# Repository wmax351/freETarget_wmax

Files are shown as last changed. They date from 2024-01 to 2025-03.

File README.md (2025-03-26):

# freETarget minimalistic

This is a fork from the forked minimalistic version. The aim is to build a version based on widely available parts only, with electronics cost of less than 30 USD. I have added an LM335 temperature sensor, and altitude compensation. 

## What is frETagret minimalistic ##

This version requires only the following electronics parts which you can source directly from you provider of choice:

**1x Arduino mega 2560**
**4x KY-037 microphone units**
**LM335 temp sensor**

This is possible due to a software change, which takes full advantage of the ATmega2560 capabilities. In the original version, shot timing is achieved using external timing infrastructure. The ATmega2560 has 6 timers, with 4 of them offering an Input Capture Unit (ICU). Using this mode, the timer values are immediately stored when a pin changes and an interrupt is fired, so there is no software jitter. One of the hurdles to overcome is in the design of the Arduino mega board, which does not connect all the ICU pins to the headers. This was overcome by bridging the respective to pins to adjacent fee ones with a fine-tipped soldering iron:

**Bridge PD4, PD5, PD6 and PD7**

**Bridge PE5, PE6, PE7**

Once done, connect the digital outputs of the microphone boards as follows:

**North: pin 38, East: pin 3, South: pin 49, West: pin 48**
**Vcc and GND to the respective Arduino pins**

**LM335 is added to A1 and GND (can use reset switch ground)**
Internal pullup is used for A1. 

For the mics to trigger all at the same level, set the pot voltage to a value of your finding (e.g. 0.380 V in my case).

Please refer to the original software for full building instructions.

A word to accuracy and precision of this version. I have not fully specified these parameters. While the timers work without a jitter (this vas verified and confirmed), there might be a diminished performance based on the selected microphone boards. Temperature sensor added back.

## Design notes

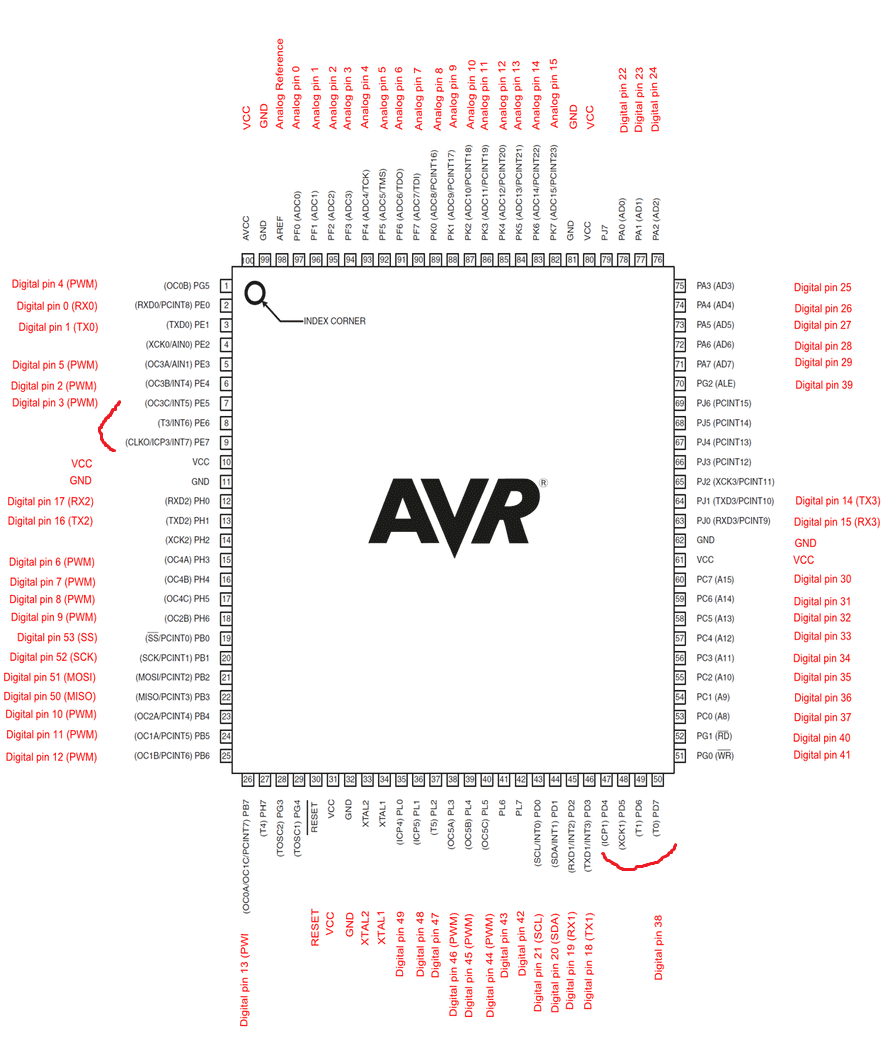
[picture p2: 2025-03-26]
PinMap2560big_Rev2.png

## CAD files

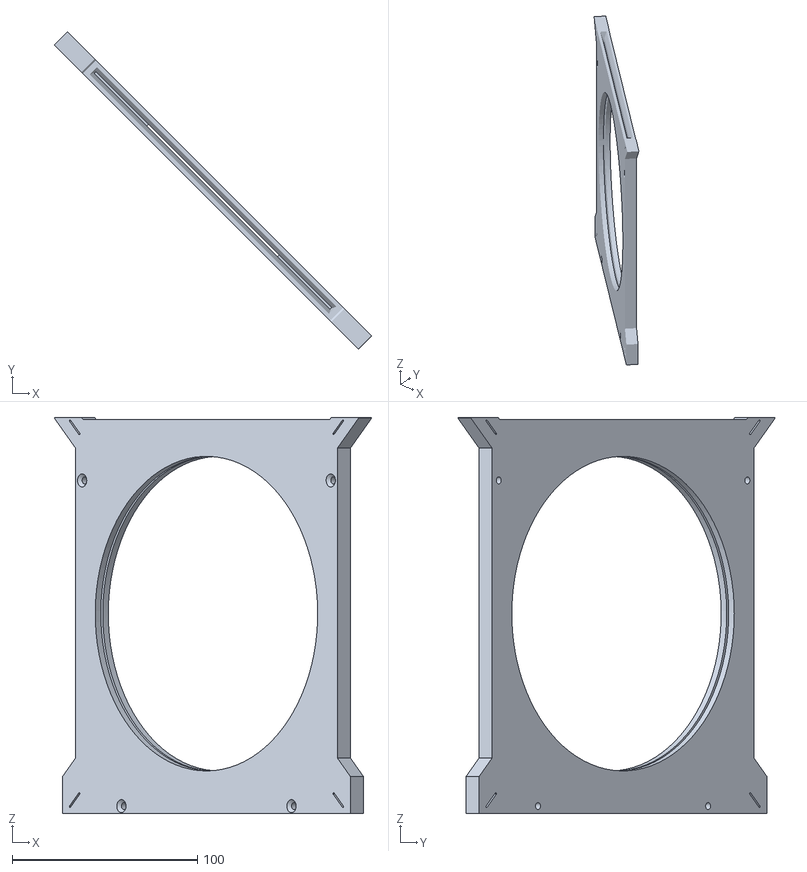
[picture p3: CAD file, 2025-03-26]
3d Print/Target Holder and Sensor Plate.stl
171.5 x 171.5 x 214.0

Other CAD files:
3d Print/Front Plate.ipt
3d Print/OldVersions/Front Plate.0002.ipt
3d Print/OldVersions/Sensor ky-037.0004.ipt
3d Print/OldVersions/Target Holder With Sensors.0013.iam
3d Print/OldVersions/Target Holder and Sensor Plate.0033.ipt
3d Print/Sensor ky-037.ipt
3d Print/Sensor ky-037_MIR.ipt
3d Print/Sensor ky-037_MIR1.ipt
3d Print/Sensor ky-037_MIR_MIR.ipt
3d Print/Sensor mounts.ipt
3d Print/Target Holder With Sensors.iam
3d Print/Target Holder and Sensor Plate.ipt

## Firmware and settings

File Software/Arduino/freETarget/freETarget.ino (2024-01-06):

/*----------------------------------------------------------------
 * 
 * freETarget        
 * 
 * Software to run the Air-Rifle / Small Bore Electronic Target
 * 
 *-------------------------------------------------------------*/
#include "freETarget.h"
#include "gpio.h"
#include "compute_hit.h"
#include "analog_io.h"
#include "json.h"
#include "EEPROM.h"
#include "nonvol.h"
#include "mechanical.h"
#include "diag_tools.h"
#include "esp-01.h"
#include "timer.h"
#include "token.h"

shot_record_t record[SHOT_STRING];          //Array of shot records
volatile unsigned int this_shot;            // Index into the shot array  
volatile unsigned int last_shot;            // Last shot processed.

double        s_of_sound;                   // Speed of sound
unsigned int  shot = 0;                     // Shot counter
unsigned int  face_strike = 0;              // Miss Face Strike interrupt count
unsigned int  is_trace = 0;                 // Turn off tracing
unsigned int  rapid_count = 0;              // Number of shots to be expected in Rapid Fire
unsigned int  tabata_state;                 // Tabata state
unsigned int  shot_number;                  // Shot Identifier
volatile unsigned long  keep_alive;         // Keep alive timer
volatile unsigned long  tabata_rapid_timer; // Tabita or Rapid fire timer
volatile unsigned long  in_shot_timer;      // Time inside of the shot window
volatile unsigned long  power_save;         // Power save timer
volatile unsigned long  token_tick;         // Token ring watchdog
volatile unsigned long  gpt;                // General purpose timer

const char* namesensor[] = { "TARGET",                                                                                           //  0
                        "1",      "2",        "3",     "4",      "5",       "6",       "7",     "8",     "9",      "10",    //  1
                        "DOC",    "DOPEY",  "HAPPY",   "GRUMPY", "BASHFUL", "SNEEZEY", "SLEEPY",                            // 11
                        "RUDOLF", "DONNER", "BLITZEN", "DASHER", "PRANCER", "VIXEN",   "COMET", "CUPID", "DUNDER",          // 18  
                        "ODIN",   "WODEN",   "THOR",   "BALDAR",                                                            // 26
                        0};
                  
const char nesw[]   = "NESW";                  // Cardinal Points
const char to_hex[] = "0123456789ABCDEF";      // Quick Hex to ASCII
static void bye(void);                         // Say good night Gracie
static long tabata(bool reset_time);           // Tabata state machine
static bool discard_tabata(void);              // TRUE if the shot should be discarded 

#define TABATA_OFF          0         // No tabata cycles at all
#define TABATA_REST         1         // Tabata is doing nothing (typically 60 seconds)
#define TABATA_WARNING      2         // Time the warning LED is on (typically 2 seconds)
#define TABATA_DARK         3         // Time the warning LED is off before the shot (typically 2 seconds)
#define TABATA_ON           4         // Time the TABATA lED is on (typically 5 seconds)

/*----------------------------------------------------------------
 * 
 * function: setup()
 * 
 * brief: Initialize the board and prepare to run
 * 
 * return: None
 * 
 *--------------------------------------------------------------*/

void setup(void) 
{    
/*
 *  Setup the serial port
 */
  Serial.begin(115200, SERIAL_8N1);
  AUX_SERIAL.begin(115200, SERIAL_8N1); 
  DISPLAY_SERIAL.begin(115200, SERIAL_8N1); 
  POST_version();                         // Show the version string on all ports
  
  init_gpio();  
  init_sensors();
  init_analog_io();
  init_timer();
  set_LED('*', '.', '.');                 // Hello World
  read_nonvol();
  
  is_trace = 0; // DLT_CRITICAL;                // Turn on tracing ToDo change back

/*
 *  Set up the port pins
 */
  timer_new(&keep_alive,    (unsigned long)json_keep_alive * ONE_SECOND); // Keep alive timer
  timer_new(&tabata_rapid_timer,   0);                                    // Free running tabata or rapid fire timer
  timer_new(&in_shot_timer, FULL_SCALE);                                  // Time inside of the shot window
  timer_new(&power_save,    (unsigned long)(json_power_save) * (long)ONE_SECOND * 60L);// Power save timer
  timer_new(&token_tick,    5 * ONE_SECOND);                              // Token ring watchdog
  timer_new(&gpt,           0);                                           // General purpose timer
  
  randomSeed( analogRead(V_REFERENCE));   // Seed the random number generator
  
/*
 * Initialize variables
 */
   set_LED('.', '.', '*');                // Hello World
   tabata(true);                          // Reset the Tabata timers
  
/*
 * Run the power on self test
 */
  set_LED('*', '.', '*');                 // Hello World
  while ( (POST_counters() == false)      // If the timers fail
              && !DLT(DLT_CRITICAL))          // and not in trace mode (DIAG jumper installed)
  {
    Serial.print(T("POST_2 Failed\r\n"));// Blink the LEDs
    blink_fault(POST_COUNT_FAILED);       // and try again
  }
  
/* 
 *  Setup the timer
 */
  set_LED('.', '*', '.');                 // Hello World

  if ( DLT(DLT_CRITICAL) )
  {
    Serial.print(T("Starting timers"));
  }

  enable_timer_interrupt();
     
/*
 * Initialize the WiFi or token ring if available
 */

   set_LED('*', '*', '.');                 // Hello World
   esp01_init();                         // Prepare the WiFi channel if installed
   
/*
 * Ready to go
 */ 
  multifunction_switch();
  set_LED('*', '*', '*');                 // Hello World
  set_LED_PWM(json_LED_PWM);
  POST_LEDs();                            // Cycle the LEDs
  set_LED(LED_READY);                     // to a client, then the RDY light is steady on
  
  if ( DLT(DLT_CRITICAL) )
  {
    Serial.print(T("Clearing serial buffers"));
  }
  while ( available_all() )
  {
    get_all();                                // Flush any garbage before we start up
  }
  
  DLT(DLT_CRITICAL); 
  Serial.print(T("Finished startup\n\r"));
  show_echo();
  return;
}

/*----------------------------------------------------------------
 * 
 * function: loop()
 * 
 * brief: Main control loop
 * 
 * return: None
 * 
 *----------------------------------------------------------------
 */
#define SET_MODE      0           // Set the operating mode
#define ARM        (SET_MODE+1)   // State is ready to ARM
#define WAIT       (ARM+1)        // ARM the circuit and wait for a shot
#define REDUCE     (WAIT+1)     // Reduce the data
#define FINISH     (REDUCE+1)     // Wait for the shot to end

unsigned int state = SET_MODE;
unsigned int old_state = ~SET_MODE;

unsigned int  sensor_status;          // Record which sensors contain valid data
unsigned int  location;               // Sensor location 

char* loop_name[] = {"SET_MODE", "ARM", "WAIT", "AQUIRE", "REDUCE", "FINISH" };

void loop() 
{
  unsigned int i, j;              // Iteration Counter
  
/*
 * First thing, handle polled devices
 */
  multifunction_switch();         // Read the switches
  tabata(false);                  // Update the Tabata state

/*
 * Take care of any commands coming through
 */

  switch (json_token )
  {
    case TOKEN_WIFI:
      esp01_receive();
      break;

    case TOKEN_MASTER:
      if ( token_tick == 0)             // Time to check the token ring?
      {
        token_init();                   // Request an enumeration
        if ( my_ring == TOKEN_UNDEF )
        {
          token_tick = ONE_SECOND * 5;  //  Waiting to start up
        }
        else
        {
          token_tick = ONE_SECOND * 60; // Just check
        }
      }

    case TOKEN_SLAVE:
      token_poll();                     // Check the token ring
      break;
  }
    
  if ( read_JSON() )
  {
    power_save = (long)json_power_save * 60L * (long)ONE_SECOND;        // Reset the power down timer if something comes in
  }

/*
 * Take care of the TCPIP keep alive
 */
 if ( (json_keep_alive != 0)
    && (keep_alive == 0) )              // Time in seconds
 {
    send_keep_alive();
    keep_alive = json_keep_alive * ONE_SECOND;
 }

/*
 * Take care of the low power mode
 */
  if ( (json_power_save != 0 ) 
       && (power_save == 0) )                         // Time in minutes
  {
    bye();                                            // Dim the lights
    power_save = (unsigned long)json_power_save * (unsigned long)ONE_SECOND * 60L;   // Came back. 
    state = SET_MODE;                                 // Reset everything just in case
  }

/*
 * Cycle through the state machine
 */
  if ( (state != old_state) 
      && DLT(DLT_APPLICATION) )
  {
    Serial.print(T("Loop State: ")); Serial.print(loop_name[state]);;
  } 
  old_state = state;
  
  switch (state)
  {
/*
 *  Check for special operating modes
 */
  default:
  case SET_MODE:    // Start of the loop
    state = set_mode();
    break;

  case ARM:         // Arm the circuit
    state = arm();
    break;

  case WAIT:        // Wait for the shot to appear
    state = wait();
    break;

  case REDUCE:     // Reduce the result of one or more shots
    state = reduce();
    break;

  case FINISH:     // Finish up the cycle by movint the witness paper
    state = finish();
    break;
  }
  
/*
 * End of the loop. return
 */
  return;
}

/*----------------------------------------------------------------
 * 
 * function: set_mode()
 * 
 * brief: Set up the modes for the next string of shots
 * 
 * return: Exit to the ARM state
 * 
 *----------------------------------------------------------------
 *
 * The shot cycle is about to start.
 * 
 * This initializes the variables.
 * 
 * The illumination LED is set depending on whether or not 
 * the Tabata or Rapid fire feature is enabled
 *
 *--------------------------------------------------------------*/
 unsigned int set_mode(void)
 {
  unsigned int i;

  for (i=0; i != SHOT_STRING; i++)
  {
    record[i].face_strike = 100;    // Disable the shot record
  }

  if ( json_tabata_enable || json_rapid_enable ) // If the Tabata or rapid fire is enabled, 
  {
    set_LED_PWM_now(0);             // Turn off the LEDs
    set_LED(LED_TABATA_ON);         // Just turn on X
    json_rapid_enable = 0;          // Disable the rapid fire
  }                                 // Until the session starts
  else
  {
    set_LED_PWM(json_LED_PWM);      // Keep the LEDs ON
  }

/*
 * Proceed to the ARM state
 */
  return ARM;                      // Carry on to the target
 }
    
/*----------------------------------------------------------------
 * 
 * function: arm()
 * 
 * brief:  Arm the circuit and check for errors
 * 
 * return: Exit to the WAIT state if the circuit is ready
 *         Stay in the ARM state if a hardware fault was detected
 * 
 *----------------------------------------------------------------
 *
 * The shot cycle is about to start.
 * 
 * This initializes the variables.
 * 
 * The illumination LED is set depending on whether or not 
 * the Tabata or Rapid fire feature is enabled
 *
 *--------------------------------------------------------------*/
unsigned int arm(void)
{
  face_strike = 0;                  // Reset the face strike count
  if ( json_send_miss
        && (json_face_strike != 0))
  {
    enable_face_interrupt();        // Turn on the face strike interrupt
  }

  stop_timers();
  arm_timers();                     // Arm the counters
  
  sensor_status = is_running();     // and immediatly read the status
  if ( sensor_status == B00001111 )         // After arming, the sensor status should all still run
  { 
    if ( DLT(DLT_APPLICATION) )
    {
      Serial.print(T("Waiting..."));
    }  
    return WAIT;                   // Fall through to WAIT
  }

/*
 * The sensors are tripping, display the error
 */
  if (!(sensor_status & B0000001))
  {
    Serial.print(T("\r\n{ \"Fault\": \"NORTH\" }"));
    set_LED(NORTH_FAILED);           // Fault code North
    delay(ONE_SECOND);
  }
  if ((!sensor_status & B00000010))
  {
    Serial.print(T("\r\n{ \"Fault\": \"EAST\" }"));
    set_LED(EAST_FAILED);           // Fault code East
    delay(ONE_SECOND);
  }
  if (!(sensor_status & B00000100))
  {
    Serial.print(T("\r\n{ \"Fault\": \"SOUTH\" }"));
    set_LED(SOUTH_FAILED);         // Fault code South
    delay(ONE_SECOND);
  }
  if (!(sensor_status & B00001000))
  {
    Serial.print(T("\r\n{ \"Fault\": \"WEST\" }"));
    set_LED(WEST_FAILED);         // Fault code West
    delay(ONE_SECOND);
  }

/*
 * Got an error, try to arm again
 */
  return ARM;
}
   
/*----------------------------------------------------------------
 * 
 * function: wait()
 * 
 * brief: Wait here for a shot to be fired
 * 
 * return: Exit to the WAIT state if the circuit is ready
 *         Stay in the ARM state if a hardware fault was detected
 * 
 *----------------------------------------------------------------
 *
 * This loop is executed indefinitly until a shot is detected
 * 
 * In this loop check
 *    - State of the WiFi interface
 *
 *--------------------------------------------------------------*/
static bool rapid_once;

unsigned int wait(void)
{
/*
 * Monitor the WiFi and blink if WiFi is present but not connected
 * Set RDY to solid red if there is a connection to the PC client
 */
  if ( ((json_token == TOKEN_WIFI) && ((esp01_is_present() == false) || esp01_connected() ))         // If the esp01 is not present, or connected
          || ((json_token != TOKEN_WIFI) && (my_ring != TOKEN_UNDEF)) )
  {
    set_LED(LED_READY);                 // to a client, then the RDY light is steady on
  }
  else
  {
    if ( (millis() / 1000) & 1 )       // Otherwise blink the RDY light
    {
      set_LED(LED_READY);
    }
    else
    {
      set_LED(LED_OFF);
    }
  }

/*
 * Check to see if the time has run out if there is a rapid fire event in progress
 */

  if (json_rapid_enable == 1)         // The rapid fire timer has been turned on
  {
    if (tabata_rapid_timer == 0 )     // Do this until the timer expires
    {
      set_LED_PWM_now(0);
      Serial.print(T("{\"RAPID_OVER\": 0}\r\n"));
      return FINISH;                   // Finish this rapid fire cycle
    }
    else
    {
      if ( rapid_once )
      {
        Serial.print(T("{\"RAPID_START\": ")); Serial.print(json_rapid_time); Serial.print(T("}\r\n"));
      }
      set_LED_PWM_now(json_LED_PWM);   // make sure the lighs are on
    }
  }

/*
 * See if any shots have arrived
 */
  if ( this_shot != last_shot )
  {
    return REDUCE;
  }
  
/*
 * All done, keep waiting
 */
  return WAIT;
}


/*----------------------------------------------------------------
 * 
 * function: reduce()
 * 
 * brief: Loop through one or more shots and present the score
 * 
 * return: Stay in the reduce state if a follow through timer is active 
 *         Jump to ARM state if more shots are ecpected
 * 
 *----------------------------------------------------------------
 *
 * This function runs in foreground and loops through the 
 * shot structure whenever there are shots in hardware to be
 * reduced.
 * 
 * In the case of rapid fire, the shot processing stops when
 * the requisite number of shots have been received.
 *
 * The shots are accumulated in the timer interrrupt which keeps
 * a queue in record[last_shot -> this shot].  The reduce()
 * loops and reduces all of the waiting shots.
 * 
 *--------------------------------------------------------------*/
unsigned int reduce(void)
{
/*
 * See if any shots are allowed to be processed
 */
  if ( discard_shot() )                                       // Tabata is on but the shot is invalid
  {
    if ( DLT(DLT_APPLICATION) )
    {
      Serial.print(T("Discarding shot: ")); Serial.print(last_shot); Serial.print(T("\r\nTrigger: ")); 
    }
    last_shot = this_shot;
    send_miss(&record[last_shot]);
    return FINISH;                                              // Throw out any shots while dark
  }
  
/*
 * Loop and process the shots that were accumulated by the timer interrupt
 */
  while (last_shot != this_shot )
  {   
    location = compute_hit(&record[last_shot]);                 // Compute the score
    
    if ( DLT(DLT_APPLICATION) )
    {
      Serial.print(T("Reducing shot: ")); Serial.print(last_shot); Serial.print(T("\r\nLocation: ")); Serial.print(location);
    }

    if ( location != MISS )                                     // Was it a miss or face strike?
    {
      if ((json_rapid_enable == 0) && (json_tabata_enable == 0))// If in a regular session, hold off for the follow through time
      {
        delay(ONE_SECOND * json_follow_through);
        if ( DLT(DLT_APPLICATION) )
        {
          Serial.print(T("Follow through: ")); Serial.print(json_follow_through);
        }
      }
      send_score(&record[last_shot]);
      rapid_red(0);
      rapid_green(1);                                           // Turn off the RED and turn on the GREEN

      if ( (json_paper_time + json_step_time) != 0 )            // Has the witness paper been enabled?
      {
        if ( ((json_paper_eco == 0)                             // ECO turned off
            || ( sqrt(sq(record[this_shot].xphys_mm) + sq(record[this_shot].yphys_mm)) < json_paper_eco )) ) // Outside the black
        {
          drive_paper();                                        // to follow through.
        }
      } 
    }
    else
    {
      if ( DLT(DLT_APPLICATION) )
      {
        Serial.print(T("Shot miss...\r\n"));
      }
      blink_fault(SHOT_MISS);
      send_miss(&record[last_shot]);
      rapid_green(0);
      rapid_red(1);                                             // Show a miss
    }

/* 
 *  Check to see if we should stop sending scores
 */
    if ( rapid_count != 0 )                                     // Decriment shots remaining
    {
      rapid_count--;                                            // in rapid fire
    }
    
/*
 * Increment and process the next
 */
    if ( (tabata_rapid_timer != 0) )                            // In a rapid fire cycle
    {
      if ( rapid_count == 0 )                                   // And the shots used up?
      {
        last_shot = this_shot;                                  // Stop processing
        break;
      }
    }
    
    last_shot = (last_shot+1) % SHOT_STRING;                    // Increment to the next active shot
  } //   End while (last_shot != this_shot )

/*
 * All done, Exit to FINISH if the timer has expired
 */
  if ( tabata_rapid_timer == 0 )
  {
    return FINISH;
  } 
  else
  {
    return WAIT;
  }
}
    
/*----------------------------------------------------------------
 * 
 * function: finish()
 * 
 * brief: Finish up the shot cycle 
 * 
 * return: Retrn to the SET_MODE state
 *
 *----------------------------------------------------------------
 *
 *--------------------------------------------------------------*/
unsigned int finish(void)
{
 
/*
 * All done, return
 */
  power_save = (long)json_power_save * 60L * (long)ONE_SECOND;     
  return SET_MODE;
}

/*----------------------------------------------------------------
 * 
 * function: tabata_enable
 * 
 * brief:    Start or stop a tabata session
 * 
 * return:   Nothing
 * 
 *----------------------------------------------------------------
 *
 * {"TABATA_WARN_ON": 1, "TABATA_WARN_OFF":5, "TABATA_ON":7, "TABATA_REST":30, "TABATA_ENABLE":1}
 * {"TABATA_WARN_ON": 2, "TABATA_WARN_OFF":2, "TABATA_ON":7, "TABATA_REST":45, "TABATA_ENABLE":1}
 * {"TABATA_ENABLE":0}
 * 
 *--------------------------------------------------------------*/
 
 void tabata_enable
  (
    unsigned int enable     // Rapid fire enable state
  )
 {
  char str[32];
  long random_wait;

/*
 * If enabled, set up the timers
 */
  if ( enable != 0 )
  {
    set_LED_PWM_now(0);                                           // Turn off the LEDs (maybe turn them on later)
  }
  else
  {
    set_LED_PWM_now(json_LED_PWM);                                // Turn on the LED to start the cycle
  }
  
  tabata_state = TABATA_OFF;                                      // Reset back to the beginning
  json_tabata_enable = enable;                                    // And enable

  sprintf(str, "{\"TABATA_ENABLED\":%d}\r\n", enable);
  output_to_all(str);

  
/*
 * All done, return
 */
  return;
 }

/*----------------------------------------------------------------
 * 
 * function: tabata
 * 
 * brief:   Implement a Tabata timer for training
 * 
 * return:  Time that the current TABATA state == TABATA_ON
 * 
 *----------------------------------------------------------------
 *
 * A Tabata timer is used to train for specific durations or time
 * of events.  For example in shooting the target should be aquired
 * and shot within a TBD seconds.
 * 
 * This function turns on the LEDs for a configured time and
 * then turns them off for another configured time and repeated
 * for a configured number of cycles
 * 
 * OFF - 2 Second Warning - 2 Second Off - ON 
 * 
 * Test JSON 
 * {"TABATA_WARN_ON": 1, "TABATA_WARN_OFF":5, "TABATA_ON":7, "TABATA_REST":30, "TABATA_ENABLE":1}
 * {"TABATA_WARN_ON": 2, "TABATA_WARN_OFF":2, "TABATA_ON":7, "TABATA_REST":45, "TABATA_ENABLE":1}
 * {"TABATA_WARN_ON": 2, "TABATA_WARN_OFF":2, "TABATA_ON":7, "TABATA_REST":45, "TABATA_ENABLE":0}
 * 
 *-------------------------------------------------------------*/

static uint16_t old_tabata_state = ~TABATA_OFF;

static long tabata
  (
  bool reset_time                     // TRUE if starting timer
  )
{
  char s[32];

  
/*
 * Reset the variables based on the arguements
 */
   if ( (json_tabata_enable == 0) || reset_time )   // Reset the timer
   {
      tabata_state = TABATA_OFF;
   }
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

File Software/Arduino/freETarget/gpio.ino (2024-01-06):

/*-------------------------------------------------------
 * 
 * gpio.ino
 * 
 * General purpose GPIO driver
 * 
 * ----------------------------------------------------*/

#include "timer.h"

const GPIO init_table[] = {   
  
  {DIP_0,       "\"DIP_0\":",    INPUT_PULLUP, 0},
  {DIP_1,       "\"DIP_1\":",    INPUT_PULLUP, 0},
  {DIP_2,       "\"DIP_2\":",    INPUT_PULLUP, 0},
  {DIP_3,       "\"DIP_3\":",    INPUT_PULLUP, 0},

  {PD4,         "\"ICP_1\":",    INPUT_PULLUP, 0 }, // N 38 connected to PD7, PD6, PD5
  {PE7,         "\"ICP_3\":",    INPUT_PULLUP, 0 }, // E 3 conencted to PE6, PE5
  {PL0,         "\"ICP_4\":",    INPUT_PULLUP, 0 }, // S 49
  {PL1,         "\"ICP_5\":",    INPUT_PULLUP, 0 }, // W 48

  {PD7,         "\"ICP_1_\":",    INPUT, 0 }, // set parallel pins to high z
  {PD6,         "\"ICP_1_\":",    INPUT, 0 },
  {PD5,         "\"ICP_1_\":",    INPUT, 0 },
  {PE6,         "\"ICP_3_\":",    INPUT, 0 },
  {PE5,         "\"ICP_3_\":",    INPUT, 0 },
    

  {LED_RDY,     "\"RDY\":",      OUTPUT, 1},
  {LED_X,       "\"X\":",        OUTPUT, 1},
  {LED_Y,       "\"Y\":",        OUTPUT, 1},

  {LED_PWM,     "\"LED_PWM\":",  OUTPUT, 0},
  {VSET_PWM,    "\"VSET_PWM\":", OUTPUT, 0},
  {RTS_U,       "\"RTS_U\":",    OUTPUT, 1},
  {CTS_U,       "\"CTS_U\":",    INPUT_PULLUP, 0},

  {FACE_SENSOR, "\"FACE\":",     INPUT_PULLUP, 0},
  
  {PAPER,      "\"PAPER\":",     OUTPUT, 1},               // 18-Paper drive active low
  
  {EOF, EOF, EOF, EOF} };


void face_ISR(void);                      // Acknowledge a face strike
void sensor_ISR(void);                    // Begin recording times for a target shot

static bool fcn_DIP_SW_A(void);           // Function to read DIP_SW_A
static bool fcn_DIP_SW_B(void);           // Function to read DIP_SW_B
static void sw_state (bool* (fcn_state)(void), unsigned long*  which_timer, void* (fcn_action)(void)); // Do something with the switches
static void send_fake_score(void);        // Send a fake score to the PC

static unsigned int dip_mask;             // Used if the MFS2 uses the DIP_0 or DIP_3
static char aux_spool[128];               // Spooling buffer from the AUX port
static char json_spool[64];               // Spool for JSON
static unsigned int  aux_spool_in, aux_spool_out; // Pointer to the spool
static unsigned int  json_spool_in, json_spool_out; // Pointer to the spool
static uint16_t T[4];                     // saves the time values


/*-----------------------------------------------------
 * 
 * function: gpio_init
 * 
 * brief: Initalize the various GPIO ports
 * 
 * return: None
 * 
 *-----------------------------------------------------
 *
 * The GPIO programming is held in a stgrucutre and 
 * copied out to the hardware on power up.
 *-----------------------------------------------------*/

void init_gpio(void)
{
  int i;

  if ( DLT(DLT_CRITICAL) ) 
  {
    Serial.print(T("init_gpio()"));  
  }
  
  i = 0;
  while (init_table[i].port != 0xff )
  {
    pinMode(init_table[i].port, init_table[i].in_or_out);
    if ( init_table[i].in_or_out == OUTPUT )
    {
      digitalWrite(init_table[i].port, init_table[i].value);
    }
    i++;
  }
  
  multifunction_init();
  disable_face_interrupt();
  set_LED_PWM(0);             // Turn off the illumination for now
  
/*
 * Special case of the witness paper
 */
  pinMode(PAPER, OUTPUT);
  paper_on_off(false);        // Turn it off
  
/*
 * All done, return
 */  
  return;
}


/*-----------------------------------------------------
 * 
 * function: read_counter
 * 
 * brief: Read specified counter register
 * 
 * return: 16 bit counter register
 * 
 *-----------------------------------------------------*/


unsigned int read_counter
  (
  unsigned int direction         // What direction are we reading?
  )
{
  // return timer value
  return T[direction];
}

/*-----------------------------------------------------
 * 
 * function: is_running
 * 
 * brief: Determine if the clocks are running
 * 
 * return: TRUE if any of the counters are running
 * 
 *-----------------------------------------------------*/

unsigned int is_running (void)
{
  unsigned int i;
  
  i = (TCCR1B & 1) +  ((TCCR3B & 1) << 1) + ((TCCR4B & 1) << 2) + ((TCCR5B & 1) <<3);

 /*
  *  Return the running mask
  */
  return i;
  }
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

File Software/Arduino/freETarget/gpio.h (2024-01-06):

/*----------------------------------------------------------------
 *
 * gpio.h
 *
 * Header file for GPIO functions
 *
 *---------------------------------------------------------------*/
#ifndef _GPIO_H_
#define _GPIO_H_

/*
 * Global functions
 */
void init_gpio(void);                                     // Initialize the GPIO ports
void arm_timers(void);                                    // Make the board ready
void clear_running(void);                                 // Clear the run flip flop 
unsigned int is_running(void);                            // Return a bit mask of running sensors 
void set_LED(int state_RDY, int state_X, int state_y);    // Manage the LEDs
unsigned int read_DIP(unsigned int dip_mask);             // Read the DIP switch register
unsigned int read_counter(unsigned int direction);
void stop_timers(void);                                   // Turn off the counter registers
void trip_timers(void);
bool read_in(unsigned int port);                          // Read the selected port
void read_timers(unsigned int* timer_counts);             // Read and return the counter registers
void drive_paper(void);                                   // Turn on the paper motor
void enable_face_interrupt();                             // Turn on the face strike interrupt
void disable_face_interrupt(void);                        // Turn off the face strike interrupt
void enable_sensor_interrupt();                           // Turn on the sensor interrupt
void disable_sensor_interrupt(void);                      // Turn off the sensor strike interrupt
void multifunction_init(void);                            // Initialize the multifunction switches
void multifunction_switch(void);                          // Handle the actions of the DIP Switch signal
void multifuction_display(void);                          // Display the MFS settings
void multifunction_wait_open(void);                       // Wait for both multifunction switches to be open
void output_to_all(char* s);                              // Multipurpose driver
void char_to_all(char ch);                                // Output a single character
void digital_test(void);                                  // Execute the digital test
void paper_on_off(bool on);                               // Turn the motor on or off
void rapid_green(unsigned int state);                     // Drive the GREEN light
void rapid_red(unsigned int state);                       // Drive the RED light
char get_all(void);                                       // Read from all of the ports
char aux_spool_read(void);                                // Read something from the AUX spool
int  aux_spool_available(void);                           // Is there something in the AUX spool
void aux_spool_put(char ch);                              // Put something into the  AUX spool
char json_spool_read(void);                               // Read something from the AUX spool
int  json_spool_available(void);                          // Is there something in the AUX spool
void json_spool_put(char ch);                             // Put something into the  AUX spool

/*
 *  Port Definitions
 */


#define RUN_PORT    PINA

#define DIP_0        9
#define RED_OUT      9                  // Rapid fire RED on DIP0
#define DIP_1       10
#define DIP_2       11
#define DIP_3       12
#define GREEN_OUT   12                  // Rapid fire GREEN on DIP3

#define RED_MASK     1                  // Use DIP 0
#define GREEN_MASK   8                  // Use DIP 3

/*
 * Multifunction Switch Use when using DIP Switch for MFS
 */
#define HOLD1(x)    LO10((x))          // Low digit        xxxx2
#define HOLD2(x)    HI10((x))          // High digit       xxx2x
#define TAP1(x)     HLO10((x))         // High Low digit   xx2xx
#define TAP2(x)     HHI10((x))         // High High digit  x2xxx
#define HOLD12(x)   HHH10((x))         // Highest digit    2xxxx

/*
 * DIP Switch Use. 
 */
//                      From DIP                   From Software
#define CALIBRATE       ((digitalRead(DIP_3) == 0)    + 0)   // 1 Go to Calibration Mode
#define DIP_SW_A        ((digitalRead(DIP_2) == 0)    + 0)   // 2 When CALIBRATE is asserted, use lower trip point
#define CAL_LOW         (DIP_SW_A)
#define DIP_SW_B        ((digitalRead(DIP_1) == 0)    + 0)   // 4 When CALIBRATE is asserted, use higher trip point
#define CAL_HIGH        (DIP_SW_B)
#define VERBOSE_TRACE   ((digitalRead(DIP_0) == 0)    + 0)   // 8 Show the verbose software trace

#define VSET_PWM     8          // VREF setting
#define CTS_U        7
#define RTS_U        6
#define LED_PWM      5          // PWM Port
#define LED_RDY      4
#define LED_X        22         // was 3
#define LED_Y        2
#define LON          1          // Turn the LED on
#define LOF          0          // Turn the LED off
#define LXX         -1          // Leave the LED alone
#define L(A, B, C)  (A), (B), (C)
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

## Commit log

2024-01-01 Just saving my first chnages, will most probably not work
    [analog_io.ino, diag_tools.h, diag_tools.ino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]
2024-01-01 Timer trigger corretly and reproducibly.
2024-01-06 First working version. Voltage on mics set to 0.380
2025-03-26 Adding Target-holder and Sensor Holder
    [Front Plate.0002.ipt, Front Plate.ipt, Sensor ky-037.0004.ipt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]
